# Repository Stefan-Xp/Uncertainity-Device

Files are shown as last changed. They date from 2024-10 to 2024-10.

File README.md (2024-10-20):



# Uncertainity-Device
Uncertainity Device - A small PCB with ESP32s2 and WS2812 compatible LEDs

Attention: This Design is not yet tested, so proceed with caution!

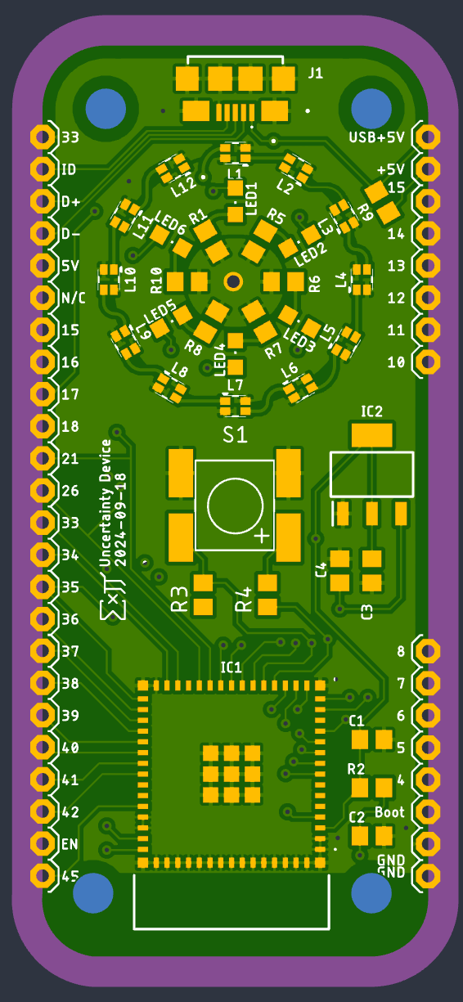
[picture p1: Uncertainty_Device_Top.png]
Top
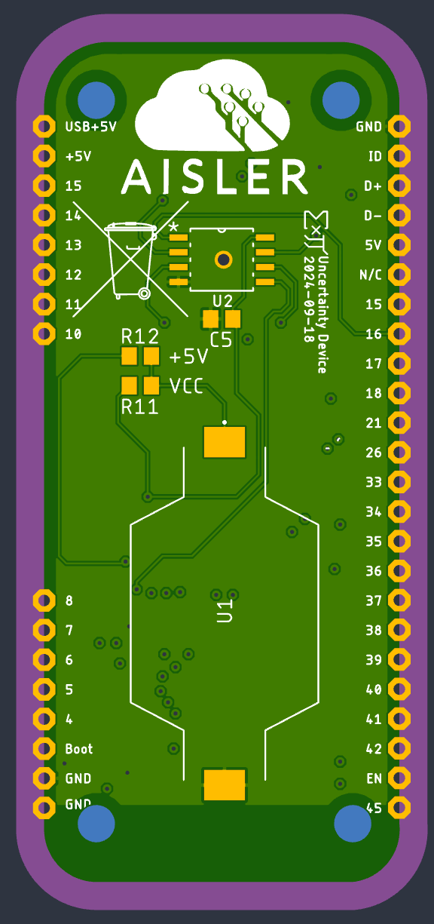
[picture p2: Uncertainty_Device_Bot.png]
Bot


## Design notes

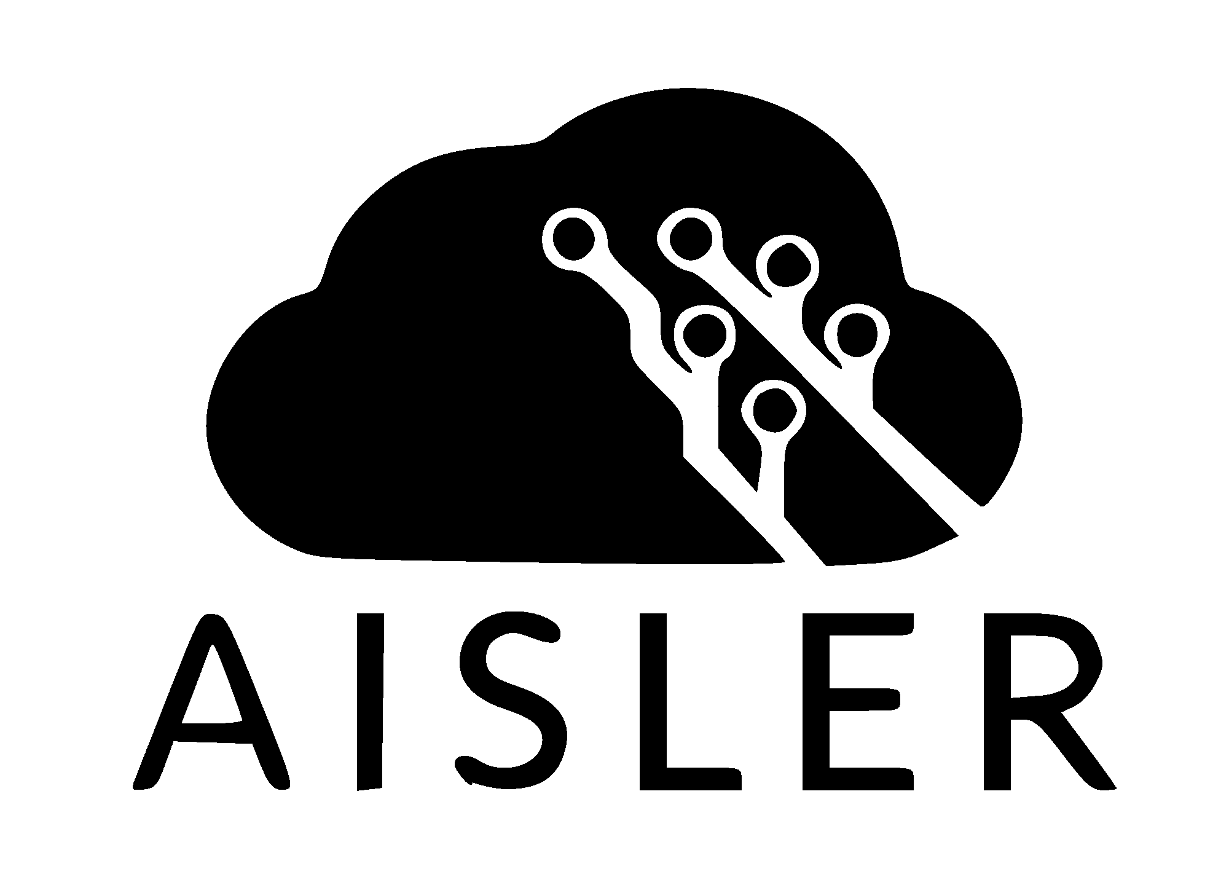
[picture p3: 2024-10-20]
Aisler_2.bmp

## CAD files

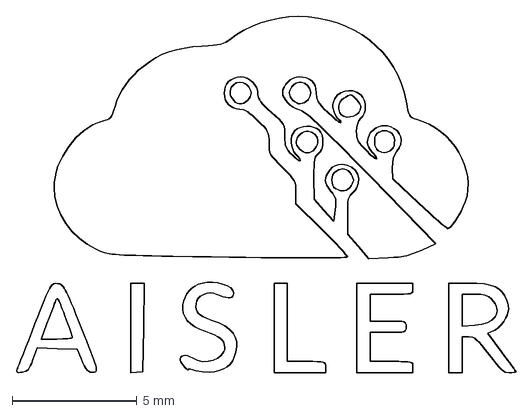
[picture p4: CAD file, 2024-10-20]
Aisler.dxf
20.0 x 14.3 mm

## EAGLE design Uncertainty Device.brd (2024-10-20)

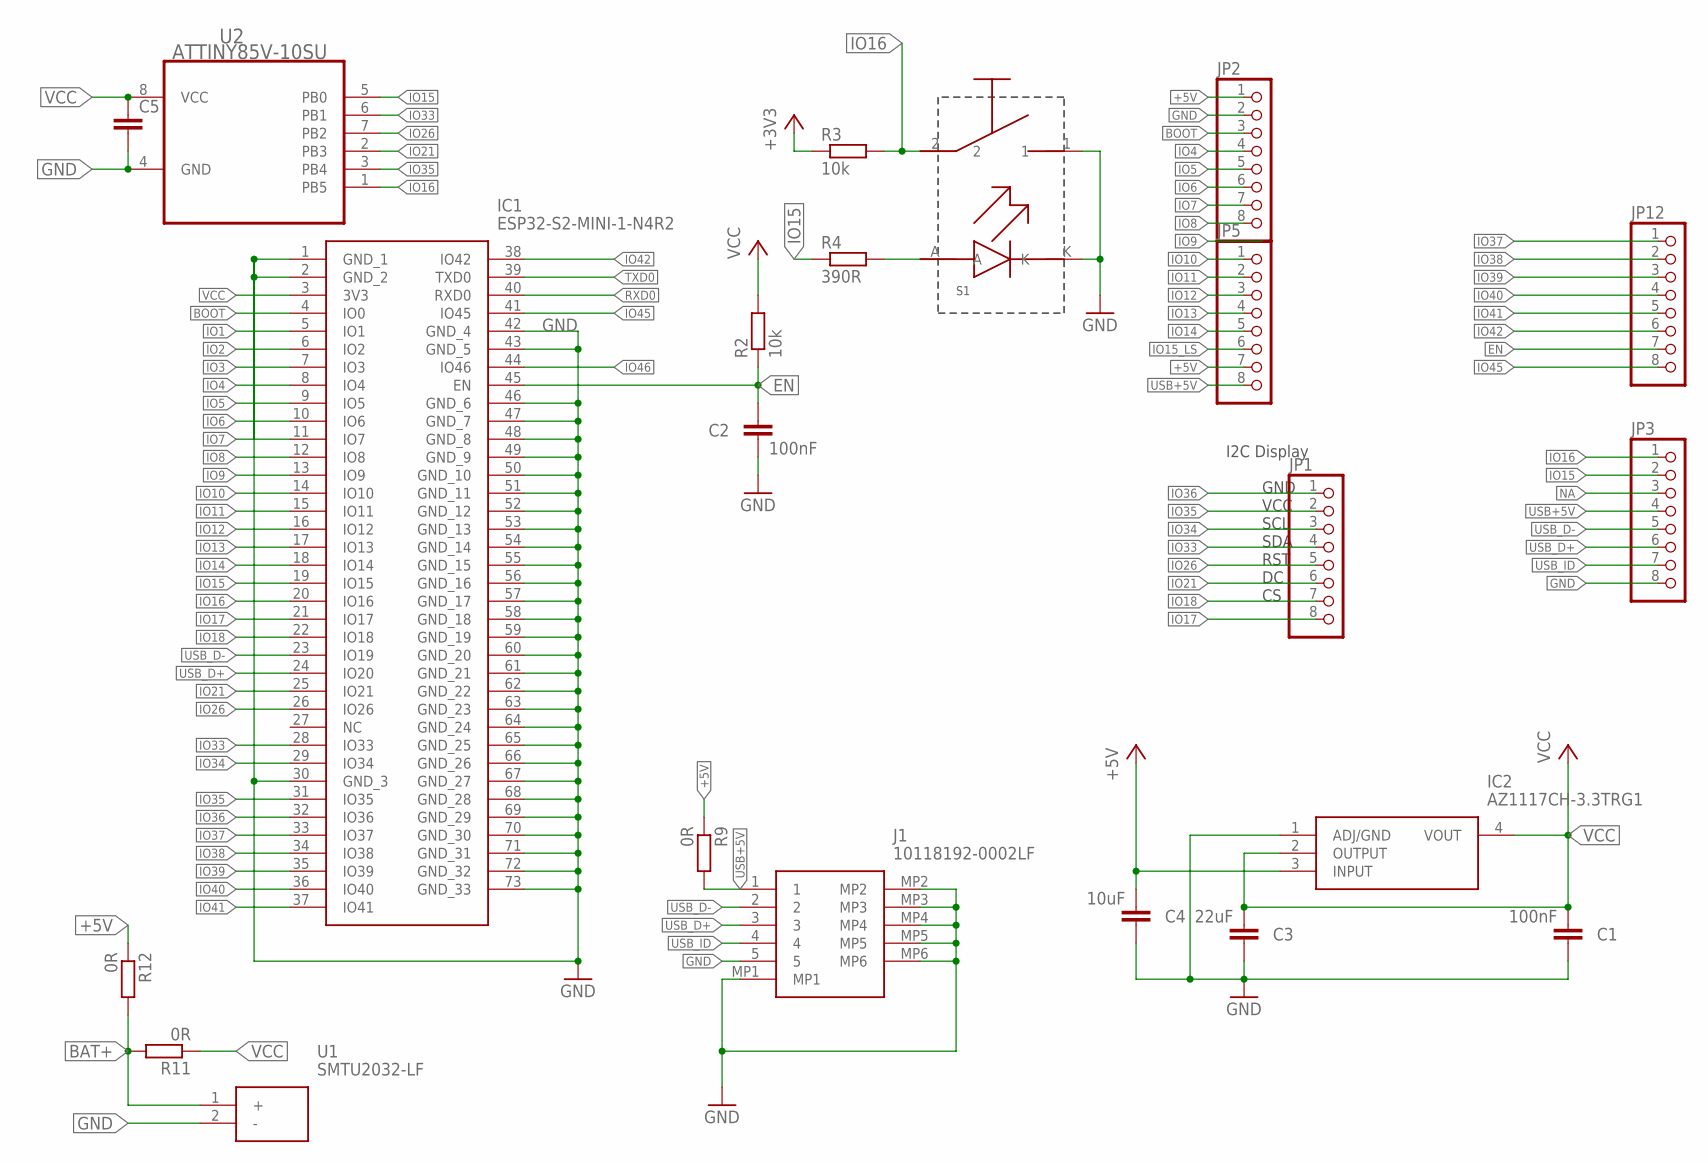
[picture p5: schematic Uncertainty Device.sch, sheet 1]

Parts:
C1, C2: 100nF; C0805
C3: 22uF; C0805
C4: 10uF; C0805
C5: C-EUC0805; C0805
IC1: ESP32-S2-MINI-1-N4R2; ESP32S2MINI1N4R2
IC2: AZ1117CH-3.3TRG1; SOT230P700X180-4N
J1: 10118192-0002LF; 101181920002LF
JP1, JP2, JP3, JP5, JP12: PINHD-1X8; 1X08
R2, R3: 10k; R0805
R4: 390R; R0805
R9, R11, R12: 0R; R0805
S1: 3006SMD; SMD
U1: SMTU2032-LF; SMTU2032LF
U2: ATTINY85V-10SU; SOIC127P798X216-8N

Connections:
+3V3: R3.1
+5V: C4.2, IC2.3 (INPUT), JP2.1, JP5.7, R9.1, R12.1
BAT+: R11.2, R12.2, U1.1 (+)
BOOT: IC1.4 (IO0), JP2.3
EN: C2.1, IC1.45 (EN), JP12.7, R2.1
GND: C1.1, C2.2, C3.1, C4.1, C5.2, IC1.1 (GND_1), IC1.2 (GND_2), IC1.30 (GND_3), IC1.42 (GND_4), IC1.43 (GND_5), IC1.46 (GND_6), IC1.47 (GND_7), IC1.48 (GND_8), IC1.49 (GND_9), IC1.50 (GND_10), IC1.51 (GND_11), IC1.52 (GND_12), IC1.53 (GND_13), IC1.54 (GND_14), IC1.55 (GND_15), IC1.56 (GND_16), IC1.57 (GND_17), IC1.58 (GND_18), IC1.59 (GND_19), IC1.60 (GND_20), IC1.61 (GND_21), IC1.62 (GND_22), IC1.63 (GND_23), IC1.64 (GND_24), IC1.65 (GND_25), IC1.66 (GND_26), IC1.67 (GND_27), IC1.68 (GND_28), IC1.69 (GND_29), IC1.70 (GND_30), IC1.71 (GND_31), IC1.72 (GND_32), IC1.73 (GND_33), IC2.1 (ADJ/GND), J1.5, J1.MP1, J1.MP2, J1.MP3, J1.MP4, J1.MP5, J1.MP6, JP2.2, JP3.8, S1.1, S1.K, U1.2 (-), U2.4 (GND); also elsewhere on the board
IO1: IC1.5 (IO1)
IO2: IC1.6 (IO2)
IO3: IC1.7 (IO3)
IO4: IC1.8 (IO4), JP2.4
IO5: IC1.9 (IO5), JP2.5
IO6: IC1.10 (IO6), JP2.6
IO7: IC1.11 (IO7), JP2.7
IO8: IC1.12 (IO8), JP2.8
IO9: IC1.13 (IO9)
IO10: IC1.14 (IO10), JP5.1
IO11: IC1.15 (IO11), JP5.2
IO12: IC1.16 (IO12), JP5.3
IO13: IC1.17 (IO13), JP5.4
IO14: IC1.18 (IO14), JP5.5
IO15: IC1.19 (IO15), JP3.2, R4.1, U2.5 (PB0)
IO15_LS: JP5.6
IO16: IC1.20 (IO16), JP3.1, R3.2, S1.2, U2.1 (PB5)
IO17: IC1.21 (IO17), JP1.8; also elsewhere on the board
IO18: IC1.22 (IO18), JP1.7; also elsewhere on the board
IO21: IC1.25 (IO21), JP1.6, U2.2 (PB3); also elsewhere on the board
IO26: IC1.26 (IO26), JP1.5, U2.7 (PB2); also elsewhere on the board
IO33: IC1.28 (IO33), JP1.4, U2.6 (PB1); also elsewhere on the board
IO34: IC1.29 (IO34), JP1.3; also elsewhere on the board
IO35: IC1.31 (IO35), JP1.2, U2.3 (PB4); also elsewhere on the board
IO36: IC1.32 (IO36), JP1.1
IO37: IC1.33 (IO37), JP12.1
IO38: IC1.34 (IO38), JP12.2
IO39: IC1.35 (IO39), JP12.3
IO40: IC1.36 (IO40), JP12.4
IO41: IC1.37 (IO41), JP12.5
IO42: IC1.38 (IO42), JP12.6
IO45: IC1.41 (IO45), JP12.8
IO46: IC1.44 (IO46)
unnamed: R4.2, S1.A
NA: JP3.3
RXD0: IC1.40 (RXD0)
TXD0: IC1.39 (TXD0)
USB+5V: J1.1, JP3.4, JP5.8, R9.2
USB_D+: IC1.24 (IO20), J1.3, JP3.6
USB_D-: IC1.23 (IO19), J1.2, JP3.5
USB_ID: J1.4, JP3.7
VCC: C1.2, C3.2, C5.1, IC1.3 (3V3), IC2.2 (OUTPUT), IC2.4 (VOUT), R2.2, R11.1, U2.8 (VCC)

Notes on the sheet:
GND
VCC
SCL
SDA
RST
I2C Display

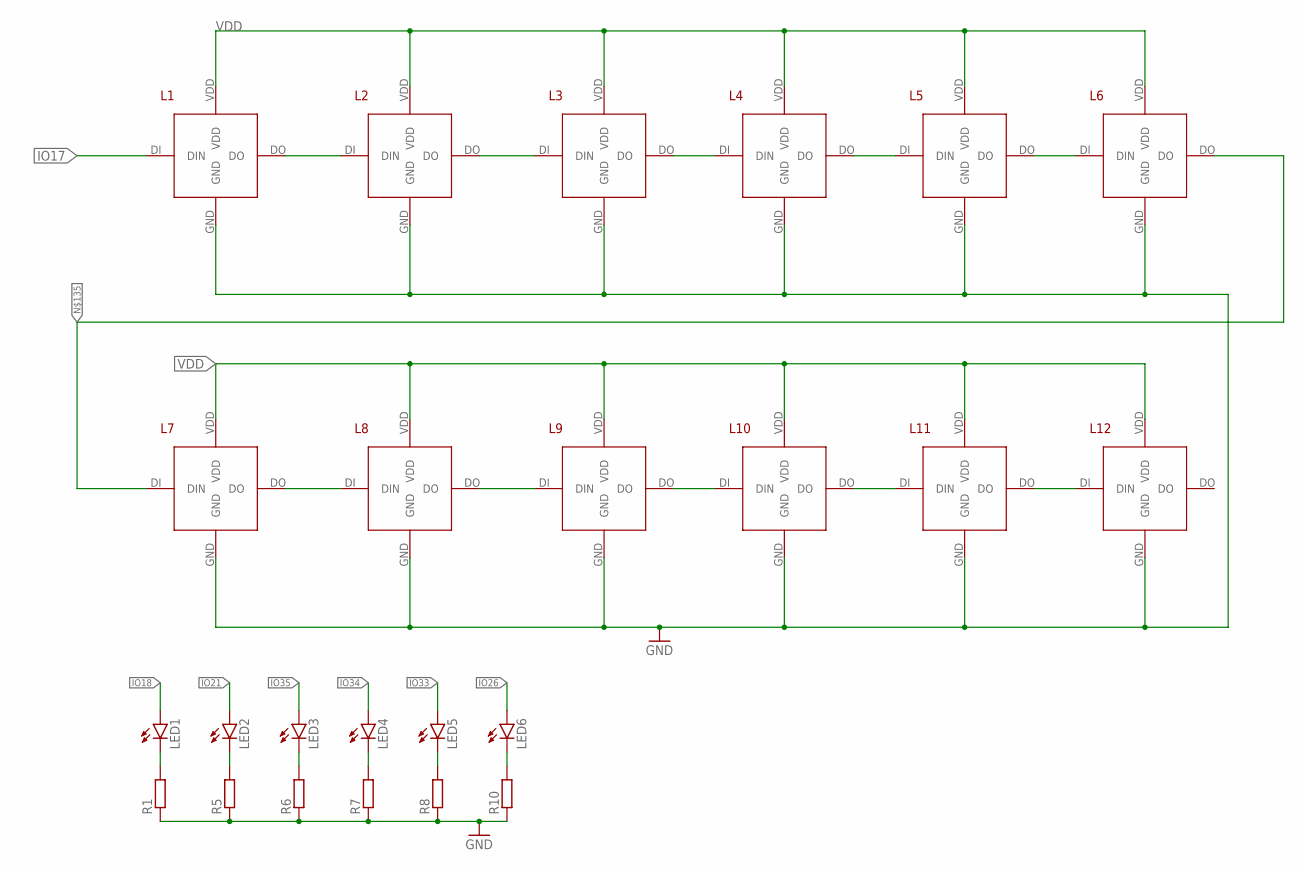
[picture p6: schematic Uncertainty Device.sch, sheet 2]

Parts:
L1, L2, L3, L4, L5, L6, L7, L8, L9, L10, L11, L12: XL-1615RGBC; XL-1615RGBC-WS2812
LED1, LED2, LED3, LED4, LED5, LED6: LEDCHIPLED_0805; CHIPLED_0805
R1, R5, R6, R7, R8, R10: R-EU_R0805; R0805

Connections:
GND: L1.GND, L2.GND, L3.GND, L4.GND, L5.GND, L6.GND, L7.GND, L8.GND, L9.GND, L10.GND, L11.GND, L12.GND, R1.1, R5.1, R6.1, R7.1, R8.1, R10.1; also elsewhere on the board
IO17: L1.DI (DIN); also elsewhere on the board
IO18: LED1.A; also elsewhere on the board
IO21: LED2.A; also elsewhere on the board
IO26: LED6.A; also elsewhere on the board
IO33: LED5.A; also elsewhere on the board
IO34: LED4.A; also elsewhere on the board
IO35: LED3.A; also elsewhere on the board
unnamed: LED1.C, R1.2
unnamed: L1.DO, L2.DI (DIN)
unnamed: L2.DO, L3.DI (DIN)
unnamed: L3.DO, L4.DI (DIN)
unnamed: L4.DO, L5.DI (DIN)
unnamed: L5.DO, L6.DI (DIN)
unnamed: L7.DO, L8.DI (DIN)
unnamed: L8.DO, L9.DI (DIN)
unnamed: L9.DO, L10.DI (DIN)
unnamed: L10.DO, L11.DI (DIN)
unnamed: L11.DO, L12.DI (DIN)
unnamed: LED2.C, R5.2
unnamed: LED3.C, R6.2
unnamed: LED4.C, R7.2
unnamed: LED5.C, R8.2
unnamed: LED6.C, R10.2
unnamed: L6.DO, L7.DI (DIN)
VDD: L1.VDD, L2.VDD, L3.VDD, L4.VDD, L5.VDD, L6.VDD, L7.VDD, L8.VDD, L9.VDD, L10.VDD, L11.VDD, L12.VDD

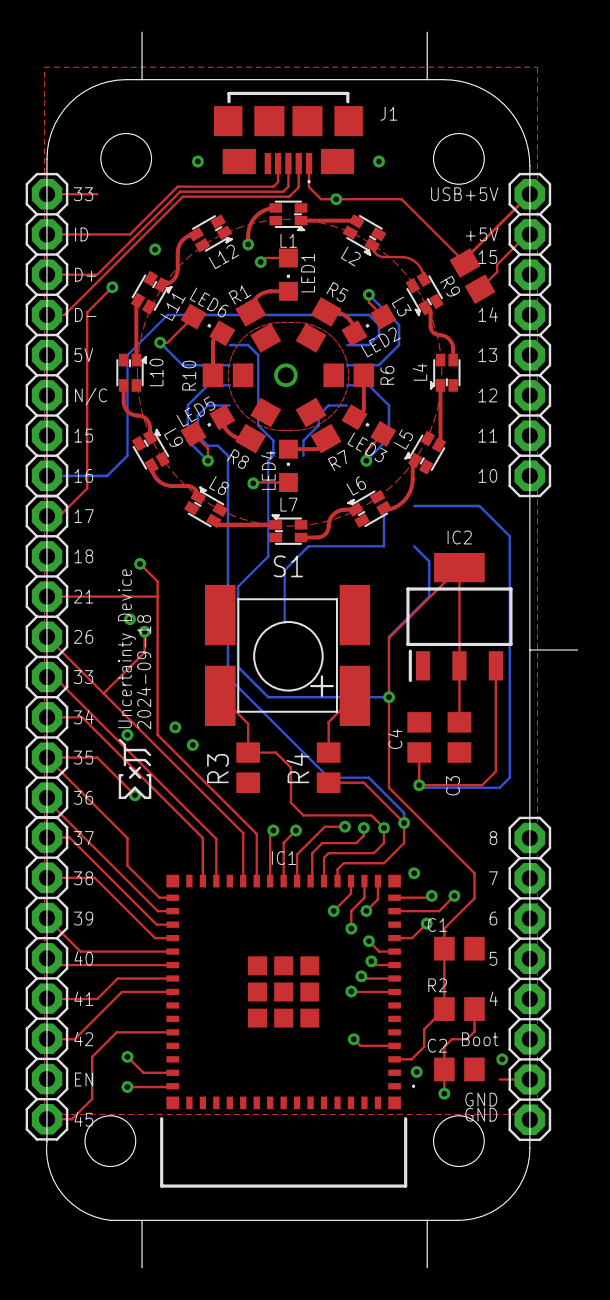
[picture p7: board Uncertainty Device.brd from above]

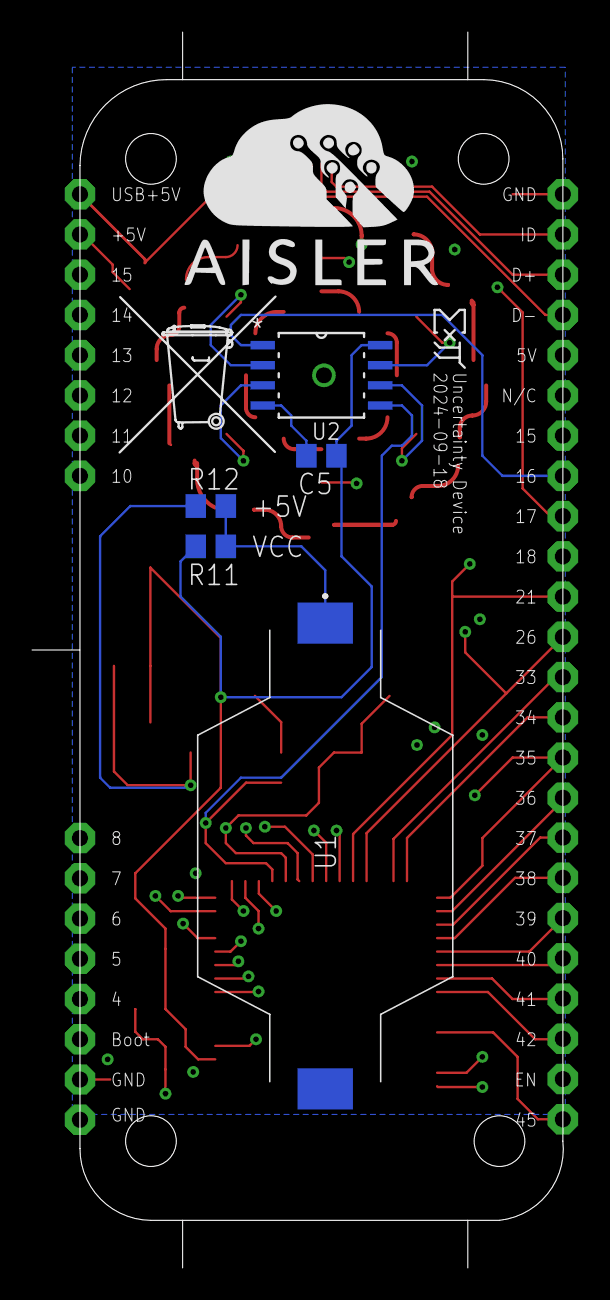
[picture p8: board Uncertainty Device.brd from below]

Board: 4 copper layers, 33.5 x 78.0 mm, 48 parts (7 on the bottom side), 56 nets.

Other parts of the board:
U$1: AISLER
U$3: TONNE_10.00

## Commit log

2024-10-20 Added Upload to Aisler button
2024-10-20 Added PCB Design Pictures
